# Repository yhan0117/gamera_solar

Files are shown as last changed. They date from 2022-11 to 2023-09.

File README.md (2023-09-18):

<!--
Hey, thanks for using the awesome-readme-template template.  
If you have any enhancements, then fork this project and create a pull request 
or just open an issue with the label "enhancement".

Don't forget to give this project a star for additional support ;)
Maybe you can mention me or this repo in the acknowledgements too
-->
<div align="center">

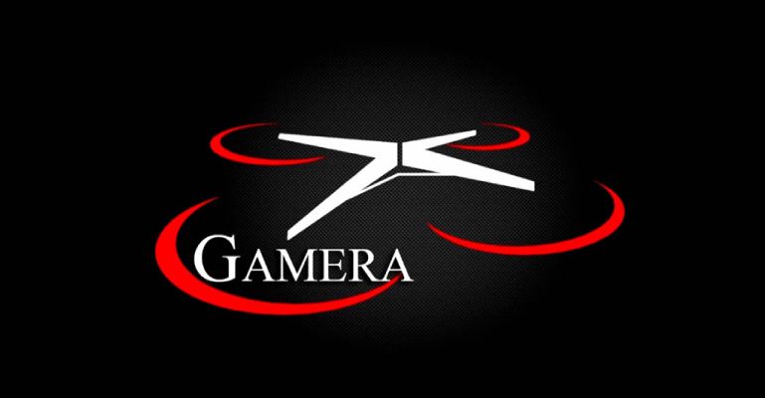
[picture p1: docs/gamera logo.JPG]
  
  <h1>Gamera Solar</h1>
  
  <p>
    An awesome README template for your projects! 
  </p>

<!-- Badges -->

<!-- Table of Contents -->
# :notebook_with_decorative_cover: Table of Contents

- [About the Project](#star2-about-the-project)
  * [Screenshots](#camera-screenshots)
  * [Tech Stack](#space_invader-tech-stack)
  * [Features](#dart-features)
  * [Color Reference](#art-color-reference)
  * [Environment Variables](#key-environment-variables)
- [Getting Started](#toolbox-getting-started)
  * [Prerequisites](#bangbang-prerequisites)
  * [Installation](#gear-installation)
  * [Running Tests](#test_tube-running-tests)
  * [Run Locally](#running-run-locally)
  * [Deployment](#triangular_flag_on_post-deployment)
- [Usage](#eyes-usage)
- [Roadmap](#compass-roadmap)
- [Contributing](#wave-contributing)
  * [Code of Conduct](#scroll-code-of-conduct)
- [FAQ](#grey_question-faq)
- [License](#warning-license)
- [Contact](#handshake-contact)
- [Acknowledgements](#gem-acknowledgements)

<!-- About the Project -->
## :star2: About the Project

<!-- Screenshots -->
### :camera: Screenshots

<div align="center"> 
  
</div>

<!-- TechStack -->
### :space_invader: Tech Stack

<details>
  <summary>Client</summary>
  <ul>
    <li><a href="https://www.typescriptlang.org/">Typescript</a></li>
    <li><a href="https://nextjs.org/">Next.js</a></li>
    <li><a href="https://reactjs.org/">React.js</a></li>
    <li><a href="https://tailwindcss.com/">TailwindCSS</a></li>
  </ul>
</details>

<details>
  <summary>Server</summary>
  <ul>
    <li><a href="https://www.typescriptlang.org/">Typescript</a></li>
    <li><a href="https://expressjs.com/">Express.js</a></li>
    <li><a href="https://go.dev/">Golang</a></li>
    <li><a href="https://nestjs.com/">Nest.js</a></li>
    <li><a href="https://socket.io/">SocketIO</a></li>
    <li><a href="https://www.prisma.io/">Prisma</a></li>    
    <li><a href="https://www.apollographql.com/">Apollo</a></li>
    <li><a href="https://graphql.org/">GraphQL</a></li>
  </ul>
</details>

<details>
<summary>Database</summary>
  <ul>
    <li><a href="https://www.mysql.com/">MySQL</a></li>
    <li><a href="https://www.postgresql.org/">PostgreSQL</a></li>
    <li><a href="https://redis.io/">Redis</a></li>
    <li><a href="https://neo4j.com/">Neo4j</a></li>
    <li><a href="https://www.mongodb.com/">MongoDB</a></li>
  </ul>
</details>

<details>
<summary>DevOps</summary>
  <ul>
    <li><a href="https://www.docker.com/">Docker</a></li>
    <li><a href="https://www.jenkins.io/">Jenkins</a></li>
    <li><a href="https://circleci.com/">CircleCLI</a></li>
  </ul>
</details>

<!-- Features -->
### :dart: Features

- Feature 1
- Feature 2
- Feature 3

<!-- Color Reference -->
### :art: Color Reference

| Color | Hex |
| --- | --- |
| Primary Color | #222831 #222831 |
| Secondary Color | #393E46 #393E46 |
| Accent Color | #00ADB5 #00ADB5 |
| Text Color | #EEEEEE #EEEEEE |

<!-- Env Variables -->
### :key: Environment Variables

To run this project, you will need to add the following environment variables to your .env file

`API_KEY`

`ANOTHER_API_KEY`

<!-- Getting Started -->
## 	:toolbox: Getting Started

<!-- Prerequisites -->
### :bangbang: Prerequisites

This project uses Yarn as package manager

```bash
 npm install --global yarn
```

<!-- Installation -->
### :gear: Installation

Install my-project with npm

```bash
  yarn install my-project
  cd my-project
```
   
<!-- Running Tests -->
### :test_tube: Running Tests

To run tests, run the following command

```bash
  yarn test test
```

<!-- Run Locally -->
### :running: Run Locally

Clone the project

```bash
  git clone https://github.com/Louis3797/awesome-readme-template.git
```

Go to the project directory

```bash
  cd my-project
```

Install dependencies

```bash
  yarn install
```

Start the server

```bash
  yarn start
```

<!-- Deployment -->
### :triangular_flag_on_post: Deployment

To deploy this project run

```bash
  yarn deploy
```

<!-- Usage -->
## :eyes: Usage

Use this space to tell a little more about your project and how it can be used. Show additional screenshots, code samples, demos or link to other resources.

```javascript
import Component from 'my-project'

function App() {
  return <Component />
}
```

<!-- Roadmap -->
## :compass: Roadmap

* [x] Todo 1
* [ ] Todo 2

<!-- Contributing -->
## :wave: Contributing

<a href="https://github.com/Louis3797/awesome-readme-template/graphs/contributors">
  
</a>

Contributions are always welcome!

See `contributing.md` for ways to get started.

<!-- Code of Conduct -->
### :scroll: Code of Conduct

Please read the [Code of Conduct](https://github.com/Louis3797/awesome-readme-template/blob/master/CODE_OF_CONDUCT.md)

<!-- FAQ -->
## :grey_question: FAQ

- Question 1

  + Answer 1

- Question 2

  + Answer 2

<!-- License -->
## :warning: License

Distributed under the no License. See LICENSE.txt for more information.

<!-- Contact -->
## :handshake: Contact

Your Name - [@twitter_handle](https://twitter.com/twitter_handle) - email@email_client.com

Project Link: [https://github.com/Louis3797/awesome-readme-template](https://github.com/Louis3797/awesome-readme-template)

<!-- Acknowledgments -->
## :gem: Acknowledgements

Use this section to mention useful resources and libraries that you have used in your projects.

 - [Shields.io](https://shields.io/)
 - [Awesome README](https://github.com/matiassingers/awesome-readme)
 - [Emoji Cheat Sheet](https://github.com/ikatyang/emoji-cheat-sheet/blob/master/README.md#travel--places)
 - [Readme Template](https://github.com/othneildrew/Best-README-Template)

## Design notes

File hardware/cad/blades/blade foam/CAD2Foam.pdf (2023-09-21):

Solidworks:
Given CAD model
In Solidworks (any CAD should work)
- Right click desired face
•
- Select “Export to DXF/DWG”
- (Relocate origin?)
- Save as desired file name and type (DXF for Mach 3) Open Mach3
- Under “File” click “LazyCam”
Open LazyCam
- Use “Open DXF” to open desired file with foam mode
- (Add step to allow for lead in/out)
- Select “Post Code”
- Save as Mach 3 file (.tap)
In Mach 3
•
- “Load G-Code
- Open desired .tap file
- Select “Tool Path” to double checkwire path
- Select “Program Run”

------------------------------------------------------------------------------------------------------------------------------------------.DAT Files
Given .dat file
Open .dat file
- “Select all”
- “Copy”
Open Microsoft Excel
- Click the arrow below “Paste”
- Under “Paste Options:” Click “Use Text Import Wizard…”
- Under “Original data type” make sure “Delimited” is selected
- Click “Next”
- Under “Data preview” you want to see two separate columns with a vertical line between. One will be your X coordinates, the other your Y coordinates. Depending on the .dat file this may already be the format as “Space” is the default delimiter. If it is not two separate columns, select “tab” or whatever was used in the .dat file to separate the columns.
- Once you have two separate columns of data, click “Finish”

•

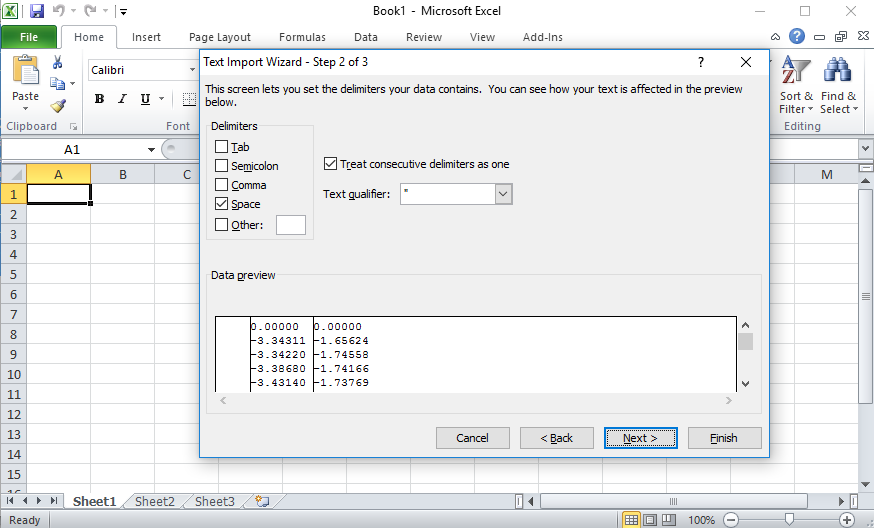
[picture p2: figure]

- If there is an empty column before you data, delete it
- Go to “File”, “Save As” and save as a “CSV (MS-DOS)(*.csv)” file with the name of your choice
- Find and open the folder containing the .csv file you just saved
- “Copy” and “Paste” the file in the same folder to duplicate it
- Rename the duplicated file to end in .scr (Ex: “SampleFile.scr”)
Open .scr file
- Add “PLINE” as the first line in the file
Open AutoCad
- Open a new drawing file
- Drag the .scr file into the drawing window. This should create a drawing that should look like the part you are trying to make.
- Type “c” to close the shape if your .scr file does not end at the same value that it begins

•

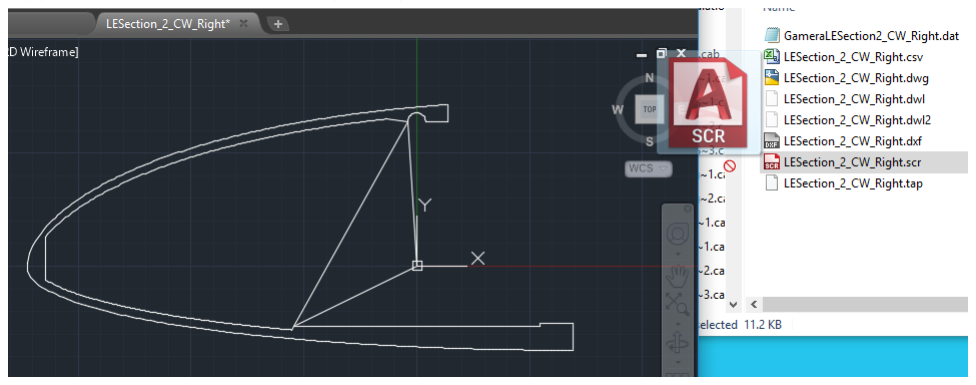
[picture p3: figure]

- Under “File” click “Save As” and save your drawing as a .dxf file (I used “AutoCad R12/LT2 DXF (*.dxf)” but do not know if there is a difference between .dxf formats)
- Close your drawing, if it prompts you to save as a drawing, you may save as a .dwg to backup
- LazyCam will not load your .dxf if it is open in AutoCad.
Open LazyCam
- Use “Open DXF” to open desired file. When prompted, select “Foam Mode”
- An image should be displayed as what you intend to cut
- Select “Post Code”
- Save as Mach 3 file (.tap)

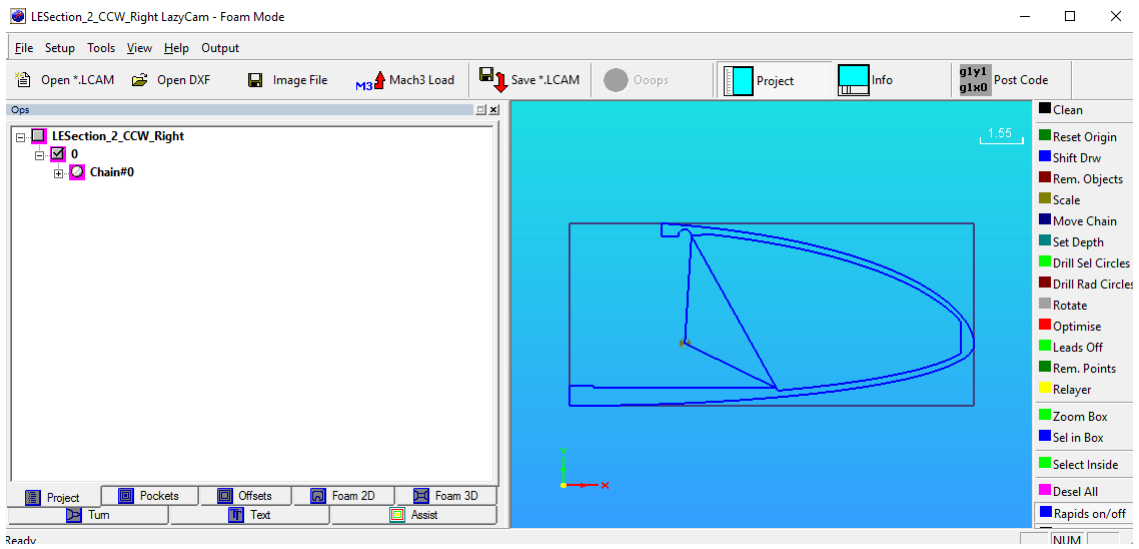
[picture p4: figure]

In Mach 3
- “Load G-Code
- Open desired .tap file
- Select “Tool Path” to double-check wire path
- Select “Program Run”

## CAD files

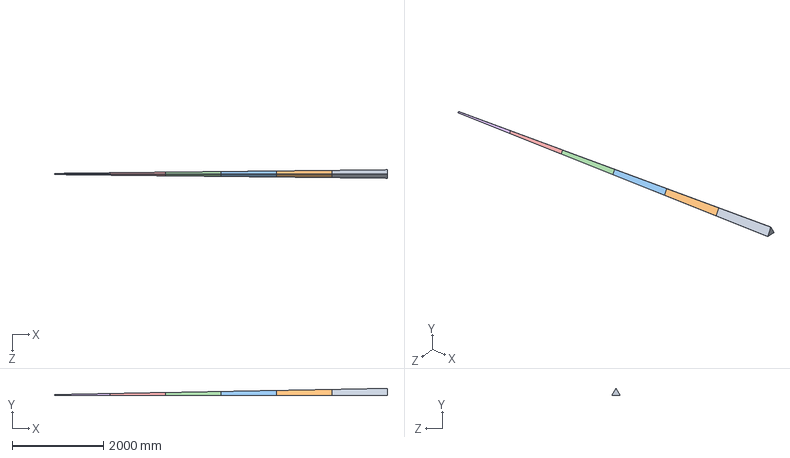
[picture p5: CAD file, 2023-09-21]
hardware/cad/blades/spar core/Blade Assembly.SLDASM
7315.0 x 159.8 x 187.7 mm
BladeSparCore1
BladeSparCore2
BladeSparCore3
BladeSparCore4
BladeSparCore5
BladeSparCore6

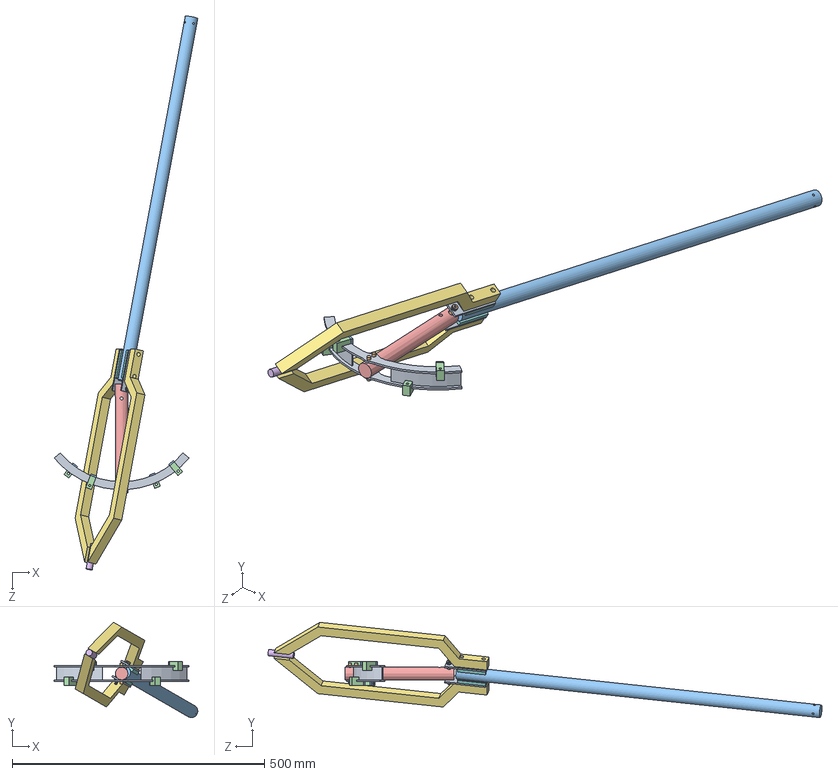
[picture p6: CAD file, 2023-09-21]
hardware/cad/rotor/landing gear/Landing_Gear.SLDASM
284.6 x 188.8 x 1097.5 mm
Hub_Crescent
Hub_Pin_A x 2
Hub_block_B x 4
Hub_block_A x 4
Hub_Shaft_CCW - Copy
LG tip-rod
LG strut x 2
Hub_plasticspacer x 2
Hub_metalspacer x 2
Shoulder Bolt
RotorShaft

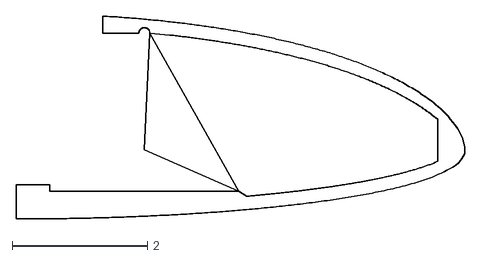
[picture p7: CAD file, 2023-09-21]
hardware/cad/blades/blade foam/dxf/LESection_3_CCW_Left.dxf
6.63 x 3.00

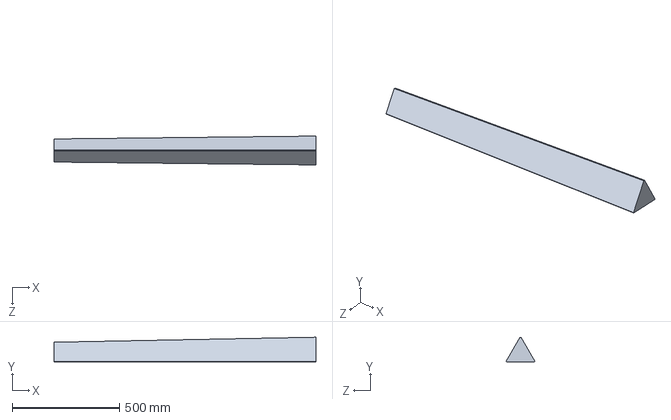
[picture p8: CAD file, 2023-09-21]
hardware/cad/blades/spar core/Core3/BladeSparCore3.SLDPRT
1219.2 x 114.4 x 134.4 mm

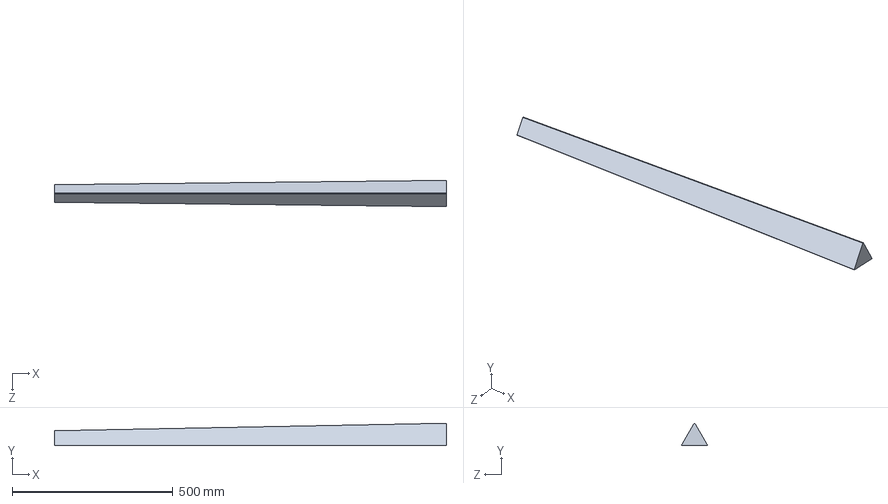
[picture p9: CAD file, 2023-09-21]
hardware/cad/blades/spar core/Core5/BladeSparCore5.SLDPRT
1219.2 x 69.9 x 81.7 mm

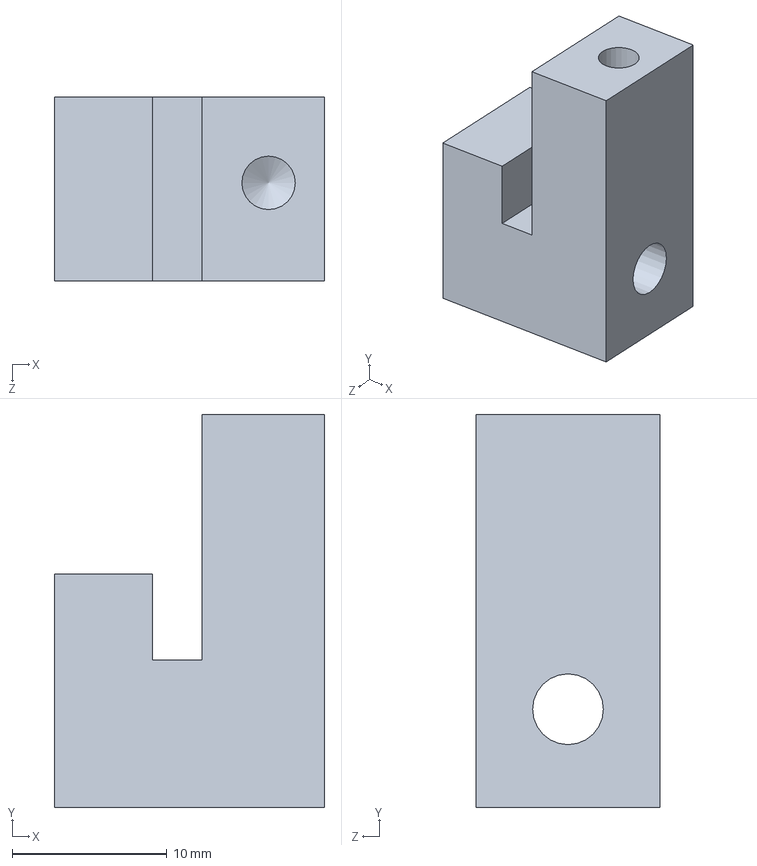
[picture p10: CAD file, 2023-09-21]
hardware/cad/rotor/hub/Hub_block_A.SLDPRT
17.5 x 25.4 x 11.9 mm

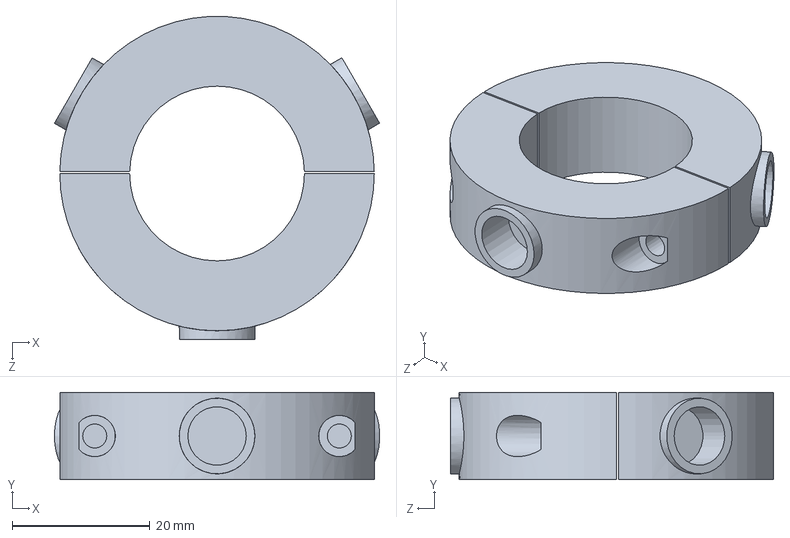
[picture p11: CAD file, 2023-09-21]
hardware/cad/rotor/shafts/shaft_collar_with_magnets.SLDPRT
47.3 x 12.7 x 47.0 mm

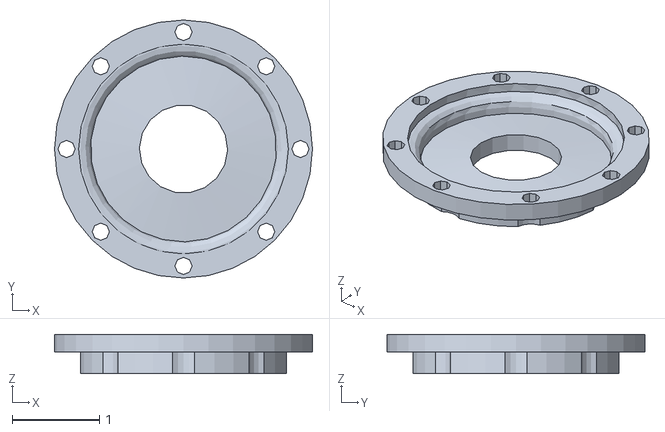
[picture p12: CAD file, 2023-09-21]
hardware/cad/rotor/transmission/Bottom Cap flat.stl
2.95 x 2.95 x 0.45

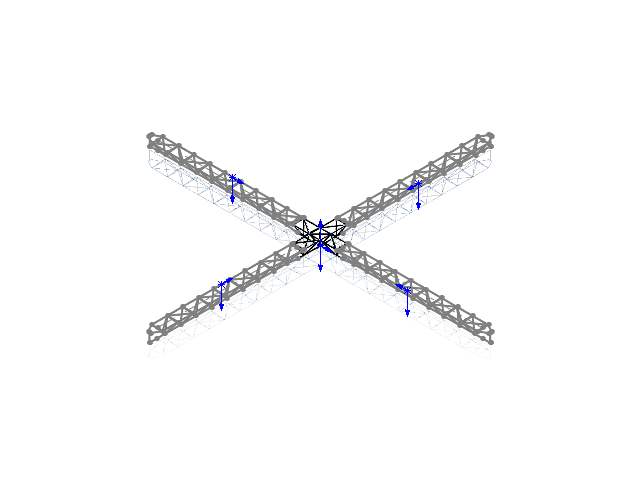
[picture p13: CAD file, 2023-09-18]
hardware/cad/airframe/airframe.SLDASM
CENTER(gamora)
ARM(Gamora) x 4

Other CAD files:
hardware/cad/blades/blade foam/section 1/LESection1_CCW_Left.dwg
hardware/cad/blades/blade foam/section 2/LESection_2_CW_Right.dwg
hardware/cad/blades/blade foam/section 3/LESection_3_CW_Right.dwg
hardware/cad/blades/blade foam/section 4/BladeSection_4_HollowTE_CW_Right.dwg
hardware/cad/blades/blade foam/section 5/BladeSection_5_CCW_Right.dwg
hardware/cad/blades/spar core/Core1 (Root)/BladeSparCore1_LeftFace.SLDPRT
hardware/cad/blades/spar core/Core2/BladeSparCore2_LeftFace.SLDPRT
hardware/cad/blades/spar core/Core4/BladeSparCore4_LeftFace.SLDPRT
hardware/cad/blades/spar core/Core6 (Tip)/BladeSparCore6_LeftFacepoints.DXF
hardware/cad/airframe/arm.SLDPRT
hardware/cad/airframe/center.SLDPRT
hardware/cad/blades/blade foam/dxf/BladeSection_4_HollowTE_CCW_Right.dxf
hardware/cad/blades/blade foam/dxf/BladeSection_4_HollowTE_CW_Right.dxf
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

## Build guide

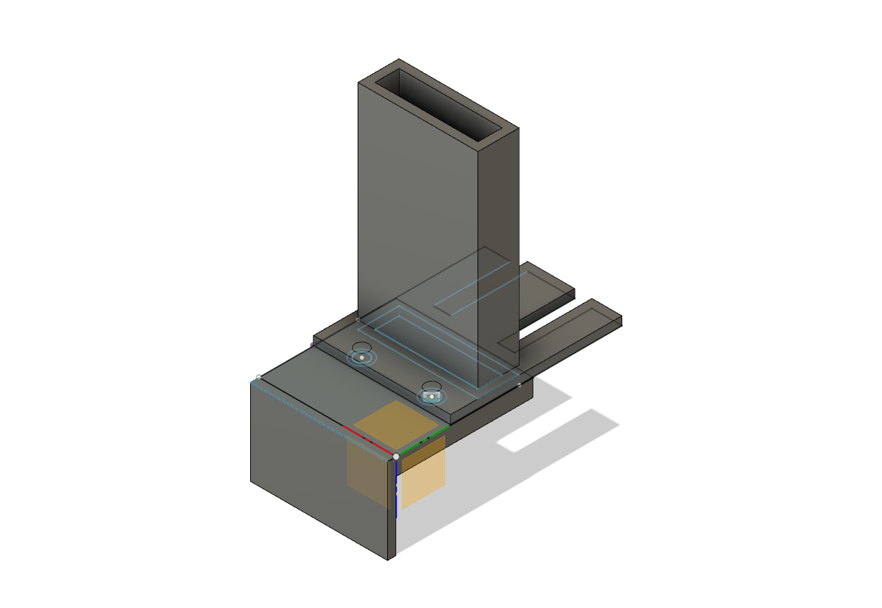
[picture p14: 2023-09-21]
testing/bbr/sensor mount/Assembly of sensor mount.png

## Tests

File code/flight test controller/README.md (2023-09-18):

firmware/src has the main.cpp file, which is the code you upload to the onboard MCU/ Arduino. In the loop() function, the script constantly monitors the Serial port (to be changed to radio) to read 4 int numbers,  do some conversions with the numbers, then send the value to the motor, via PWM with the command servo.write().\
control/read_keyboard.py is essentially the "controller" that uses the arrow keys as the joystick. It also loops indefinitely (in main function), read the keyboard input, keep track of the motor commands (the 4 int variables), and send to the MCU via Serial. \
The radio directory has two arduino files we used for testing the nRF24L01 modules. There's a transmit file and a receiver file, and those need to be uploaded to two separate MCUs, both connected to their own radio module based on the following schematic. Make sure you have steady and sufficient power source. More details on how to use those modules can be found in [Dejan's Blog](https://howtomechatronics.com/tutorials/arduino/arduino-wireless-communication-nrf24l01-tutorial/)\
schematic

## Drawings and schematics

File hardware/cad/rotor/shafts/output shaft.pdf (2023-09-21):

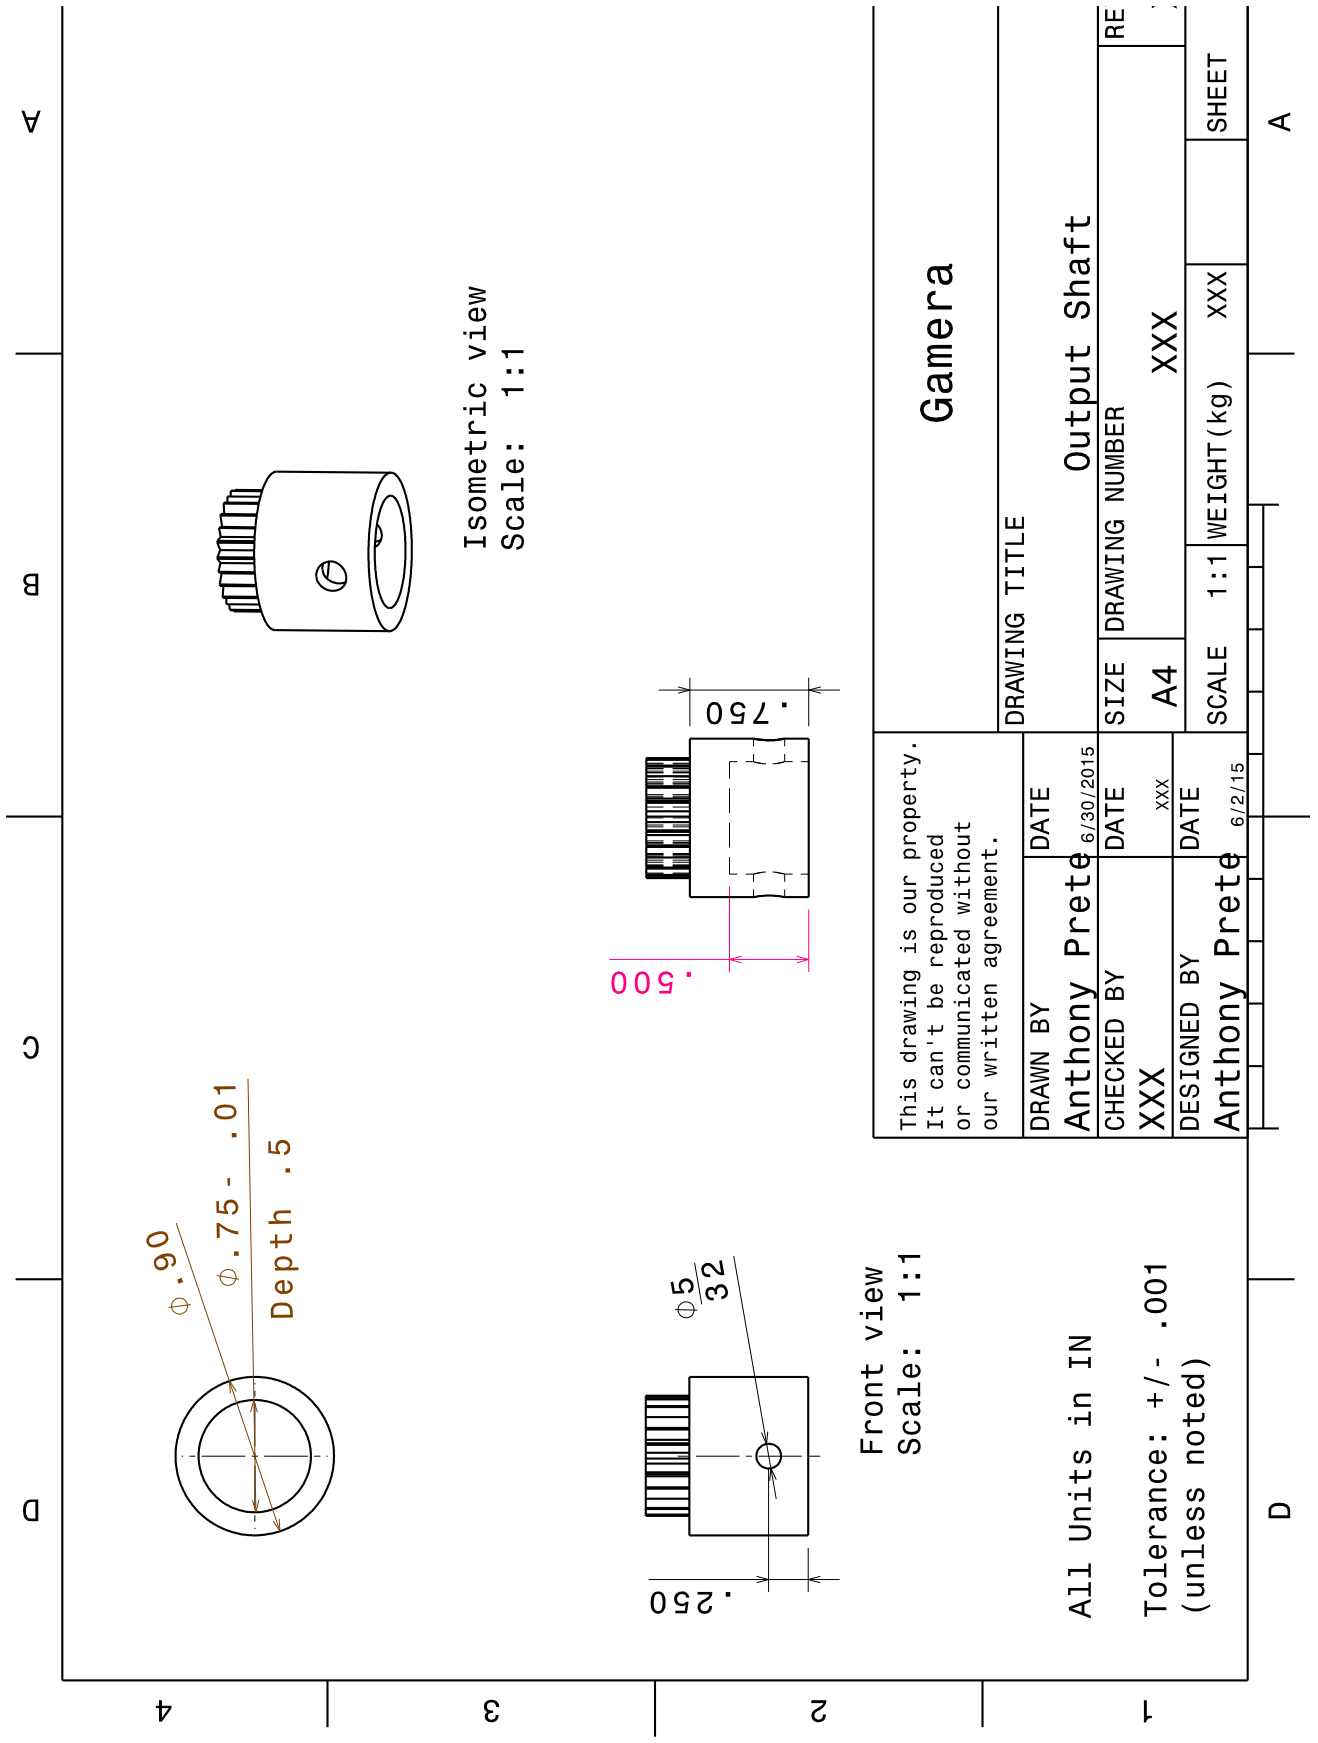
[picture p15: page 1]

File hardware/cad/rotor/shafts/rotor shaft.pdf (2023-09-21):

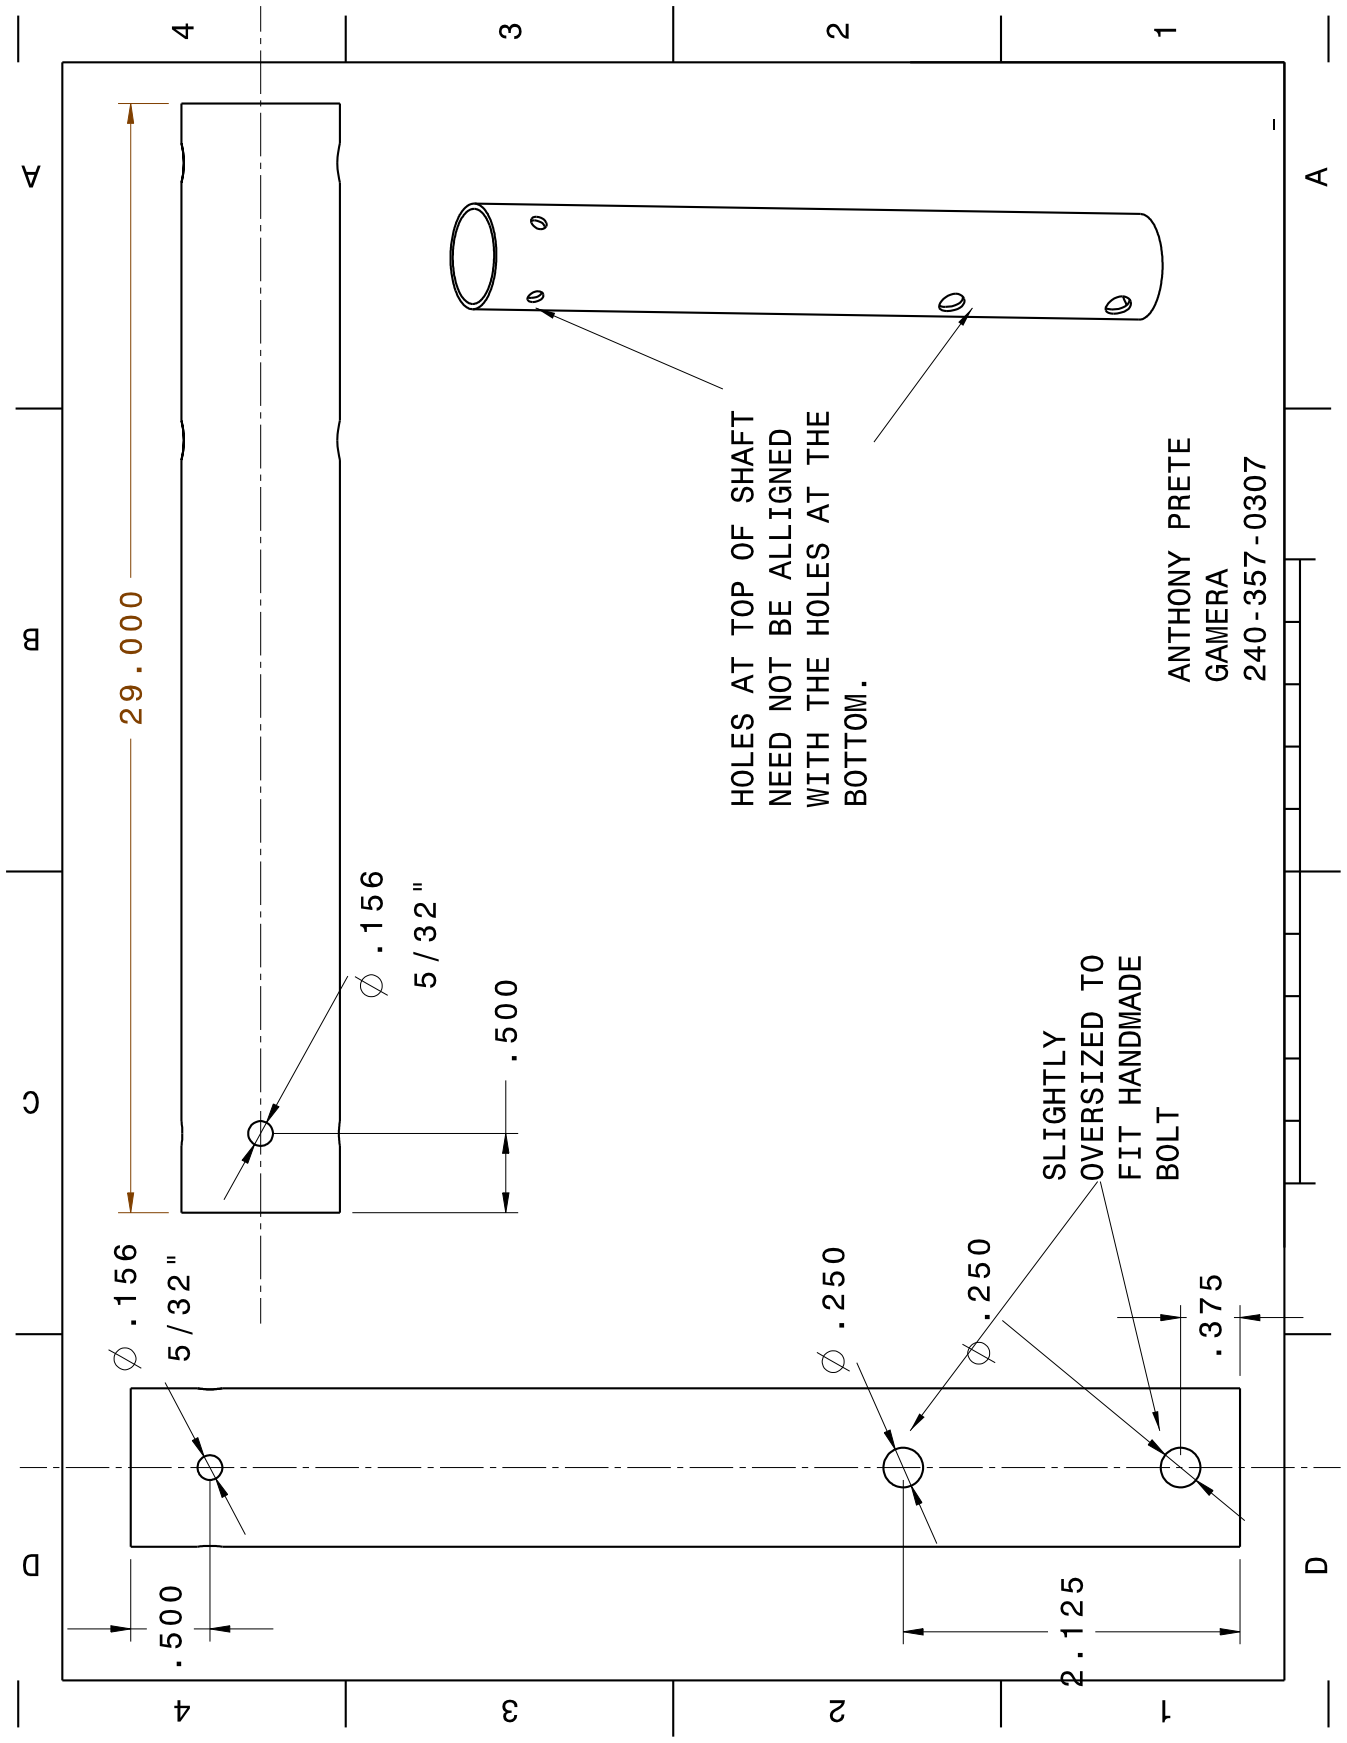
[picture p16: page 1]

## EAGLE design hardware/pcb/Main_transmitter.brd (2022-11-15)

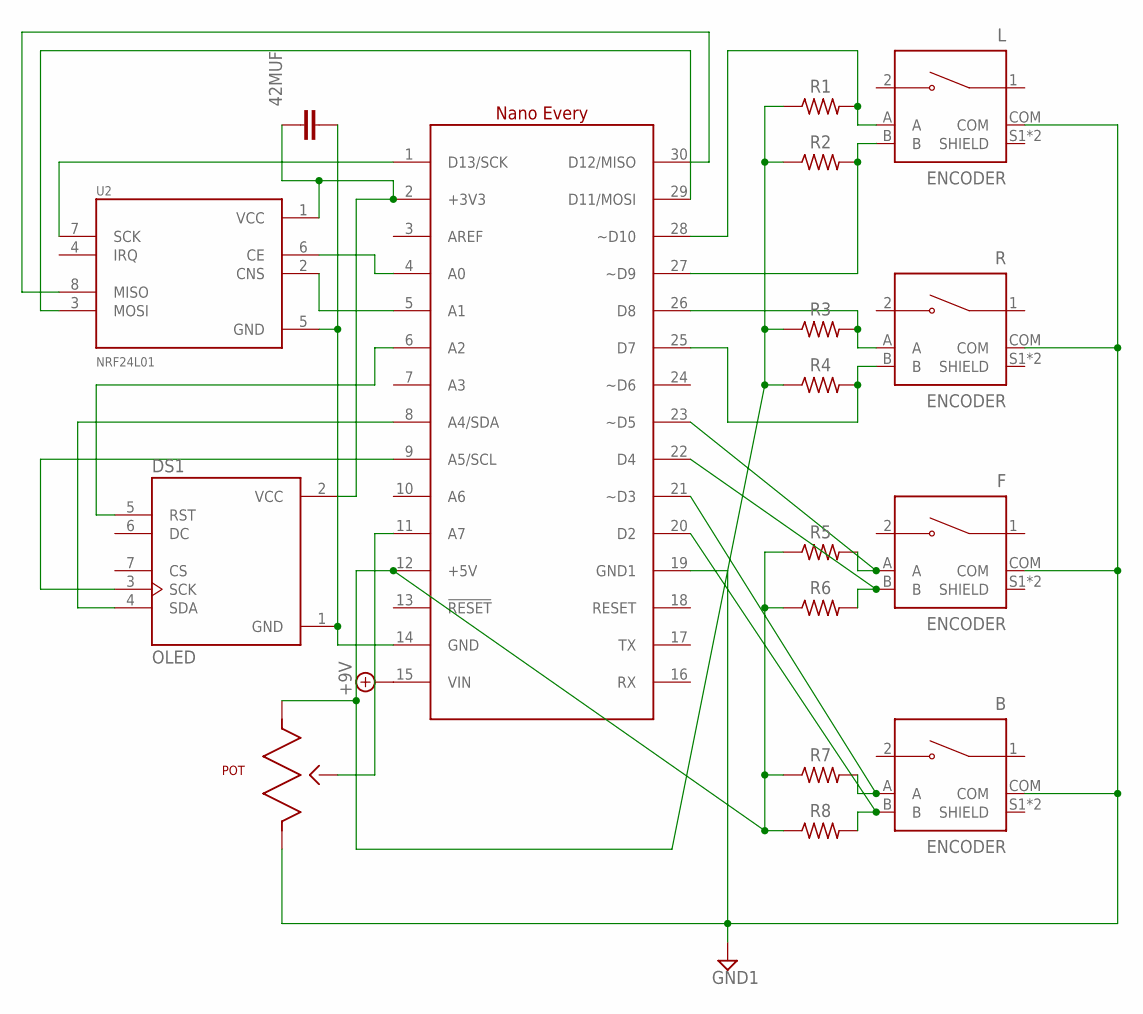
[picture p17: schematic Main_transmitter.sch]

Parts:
42MUF: C_RADIAL-12.5MM-DIA; CAPRD550W60D1025H1250B
B: ENCODER; XDCR_PEC11R-4215F-S0024
DS1: OLED
F: ENCODER; XDCR_PEC11R-4215F-S0024
L: ENCODER; XDCR_PEC11R-4215F-S0024
POT: POTENTIOMETER; P160
R: ENCODER; XDCR_PEC11R-4215F-S0024
R1, R2, R3, R4, R5, R6, R7, R8: R-US_AXIAL-7.2MM-PITCH; RESAD724W46L381D178B
U1: ARDUINONANO; NANO
U2: NRF24L01

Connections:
unnamed: L.A, R1.2, U1.28 (~D10)
unnamed: L.B, R2.2, U1.27 (~D9)
unnamed: R.A, R3.2, U1.26 (D8)
unnamed: R.B, R4.2, U1.25 (D7)
unnamed: F.A, R5.2, U1.23 (~D5)
unnamed: U1.4 (A0), U2.6 (CE)
unnamed: F.B, R6.2, U1.22 (D4)
unnamed: U1.5 (A1), U2.2 (CNS)
unnamed: B.A, R7.2, U1.21 (~D3)
unnamed: B.B, R8.2, U1.20 (D2)
unnamed: B.COM, F.COM, L.COM, POT.3, R.COM, U1.19 (GND1)
unnamed: U1.30 (D12/MISO), U2.8 (MISO)
unnamed: U1.29 (D11/MOSI), U2.3 (MOSI)
unnamed: POT.2, U1.11 (A7)
unnamed: DS1.3 (SCK), U1.9 (A5/SCL)
unnamed: DS1.4 (SDA), U1.8 (A4/SDA)
unnamed: 42MUF.1, DS1.2 (VCC), U1.2 (+3V3), U2.1 (VCC)
unnamed: 42MUF.2, DS1.1 (GND), U1.14 (GND), U2.5 (GND)
unnamed: U1.1 (D13/SCK), U2.7 (SCK)
unnamed: DS1.5 (RST), U1.6 (A2)
unnamed: POT.1, R1.1, R2.1, R3.1, R4.1, R5.1, R6.1, R7.1, R8.1, U1.12 (+5V)
VIN: U1.15 (VIN)

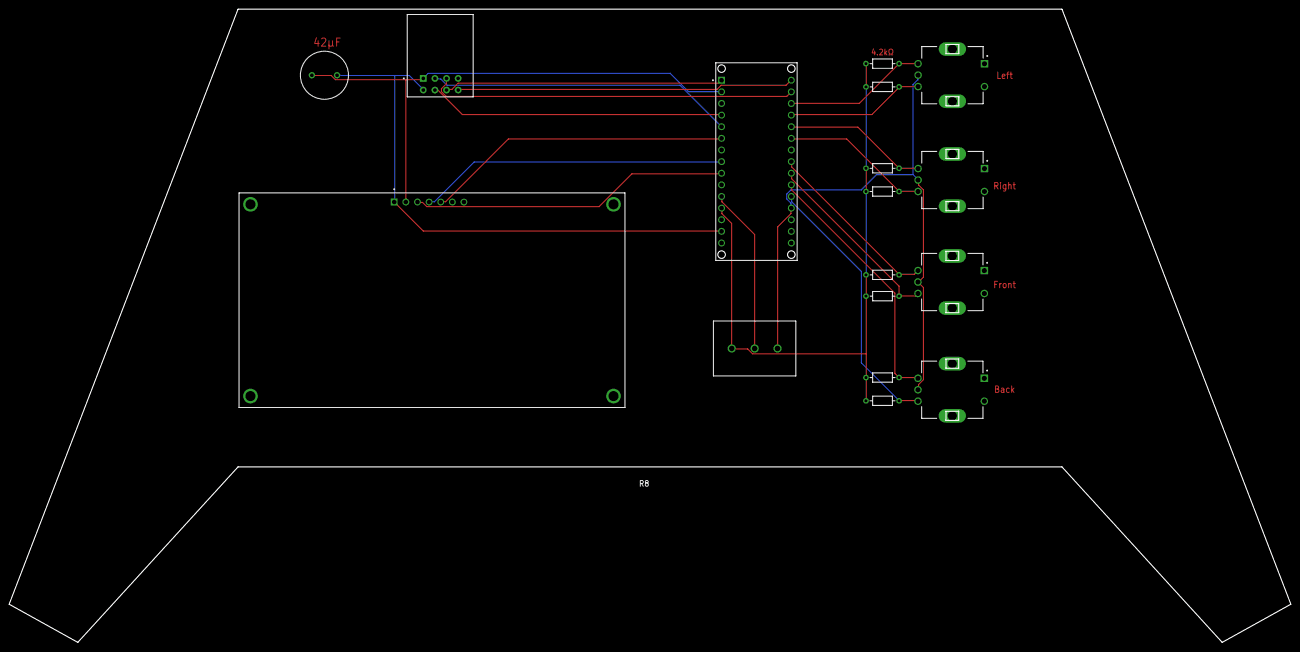
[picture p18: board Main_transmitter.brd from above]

Board: 2 copper layers, 280.0 x 138.3 mm, 17 parts (0 on the bottom side), 21 nets.

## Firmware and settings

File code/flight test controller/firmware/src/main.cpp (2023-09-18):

/*
BLDC controller based on keyboard input
*/

#include <Arduino.h>
#include <Servo.h>

#define MIN_SIGNAL 800
#define MAX_SIGNAL 2200

// read key vars
char key;
const int BUFFER_SIZE = 1;
char buf[2];

// motor struct
const int MOTOR_PIN[4] = {3,5,6,9};
struct MOTOR{
  Servo motor;
  int power;
};
struct MOTOR allMotors[4];

// function prototypes
void calibrate();
void quit();
void displayAllMotors();

// setup 
void setup() {
  // general config
  Serial.begin(115200);
  Serial.setTimeout(20);  
  pinMode(13, OUTPUT);

  // initialize motor
  for (int i = 0; i < 4; i++) {
    allMotors[i].motor.attach(MOTOR_PIN[i]);
    allMotors[i].power = MIN_SIGNAL;
    allMotors[i].motor.writeMicroseconds(MIN_SIGNAL);
  }

  // sync with main
  Serial.print(1);

  // wait for prompt to start 
  while (buf[1] != '\t')
      Serial.readBytes(buf, 2);
  buf[1] = ' ';

  // calibrate if required
  if (buf[0] == 'c')
    calibrate(); 

  // begin program
  Serial.println(0);
  // flash LED x5
  for(int i = 0; i < 5; i++) {
    digitalWrite(13,HIGH); 
    delay(100);
    digitalWrite(13,LOW);
    delay(100);
  }
}

// loop
void loop() {
  // reading key takes total of 20ms (based on timeout)
  Serial.readBytes(buf, BUFFER_SIZE);
  key = buf[0];

  switch (key) {
    // increase total throttle
    case 'H':
      for (int i = 0; i < 4; i++) {
        allMotors[i].power += 5;
        allMotors[i].power >= MAX_SIGNAL ? allMotors[i].power = MAX_SIGNAL : allMotors[i].power = allMotors[i].power; // saturate
      }
      displayAllMotors();
      digitalWrite(13,HIGH);  
      break;

    // decrease total throttle
    case 'P':
      for (int i = 0; i < 4; i++) {
        allMotors[i].power -= 5;
        allMotors[i].power <= MIN_SIGNAL ? allMotors[i].power = MIN_SIGNAL : allMotors[i].power = allMotors[i].power; // saturate
      }
      displayAllMotors();
      digitalWrite(13,HIGH);  
      break;

    // individual motor control => increase
    // blue
    case 'w':
      allMotors[0].power += 5;
      allMotors[0].power >= MAX_SIGNAL ? allMotors[0].power = MAX_SIGNAL : allMotors[0].power = allMotors[0].power; // saturate
      displayAllMotors();
      digitalWrite(13,HIGH);  
      break;

    // red
    case 'a':
      allMotors[1].power += 5;
      allMotors[1].power >= MAX_SIGNAL ? allMotors[1].power = MAX_SIGNAL : allMotors[1].power = allMotors[1].power; // saturate
      displayAllMotors();
      digitalWrite(13,HIGH);  
      break;

    // yellow
    case 's':
      allMotors[2].power += 5;
      allMotors[2].power >= MAX_SIGNAL ? allMotors[2].power = MAX_SIGNAL : allMotors[2].power = allMotors[2].power; // saturate
      displayAllMotors();
      digitalWrite(13,HIGH);  
      break;

    // pink
    case 'd':
      allMotors[3].power += 5;
      allMotors[3].power >= MAX_SIGNAL ? allMotors[3].power = MAX_SIGNAL : allMotors[3].power = allMotors[3].power; // saturate
      displayAllMotors();
      digitalWrite(13,HIGH);  
      break;

    // decrease
    // blue
    case 'W':
      allMotors[0].power -= 5;
      allMotors[0].power <= MIN_SIGNAL ? allMotors[0].power = MIN_SIGNAL : allMotors[0].power = allMotors[0].power; // saturate
      displayAllMotors();
      digitalWrite(13,HIGH);  
      break;

    // red
    case 'A':
      allMotors[1].power -= 5;
      allMotors[1].power <= MIN_SIGNAL ? allMotors[1].power = MIN_SIGNAL : allMotors[1].power = allMotors[1].power; // saturate
      displayAllMotors();
      digitalWrite(13,HIGH);  
      break;

    // yellow
    case 'S':
      allMotors[2].power -= 5;
      allMotors[2].power <= MIN_SIGNAL ? allMotors[2].power = MIN_SIGNAL : allMotors[2].power = allMotors[2].power; // saturate
      displayAllMotors();
      digitalWrite(13,HIGH);  
      break;

    // pink
    case 'D':
      allMotors[3].power -= 5;
      allMotors[3].power <= MIN_SIGNAL ? allMotors[3].power = MIN_SIGNAL : allMotors[3].power = allMotors[3].power; // saturate
      displayAllMotors();
      digitalWrite(13,HIGH);  
      break;

    // quit program
    case 'Q':
      quit();
  }

  delay(5);
  // update throttle
  for (int i = 0; i < 4; i++) {
    allMotors[i].motor.writeMicroseconds(allMotors[i].power);
  }  
  digitalWrite(13,LOW);
}

// ESC calibration routine
void calibrate() {
  // send max throttle
  for (int i = 0; i < 4; i++) {
    allMotors[i].motor.writeMicroseconds(MAX_SIGNAL);
  }

  // calibration begin, plug in power here
  // represented by 2
  Serial.println(2);

  // flash LED as indication
  for(int i = 0; i < 3; i++) {
    digitalWrite(13,HIGH); 
    delay(1000);
    digitalWrite(13,LOW);
    delay(1000);
  }

  // wait for tone to end then input
  while (buf[1] != '\t')
      Serial.readBytes(buf, 2);
  buf[1] = ' ';

  // sending min throttle
  // represented by 3
  Serial.println(3);
  for (int i = 0; i < 4; i++) {
    allMotors[i].motor.writeMicroseconds(MIN_SIGNAL);
  }
  // flash LED to indicate completion
  for(int i = 0; i < 3; i++) {
    digitalWrite(13,HIGH); 
    delay(1000);
    digitalWrite(13,LOW);
    delay(1000);
  }

  // power cycle now

  // wait for prompt to start
  while (buf[1] != '\t')
    Serial.readBytes(buf, 2);
}

void quit() {
  Serial.println(4);

  // LED 
  for (int i = 200; i > 0; i--) {
    float DC = i / 200.0;
    digitalWrite(13, 1);
    delayMicroseconds(floor(2000 * DC));
    digitalWrite(13, 0);
    delayMicroseconds(floor(2000 * (1 - DC)));
  }

  // decelerating motors
  int dp[4];
  for (int i = 0; i < 4; i++) { 
    dp[i]= allMotors[i].power - MIN_SIGNAL;
  }

  for (int i = 0; i <= 100; i++) {
    for (int i = 0; i < 4; i++) { 
      allMotors[i].power -= dp[i]/100;
      allMotors[i].motor.writeMicroseconds(allMotors[i].power);
    }
    delay(50);
  }

  // detach motors and Serial just in case
  Serial.println(5);
  for (int i = 0; i < 4; i++) { 
    allMotors[i].motor.detach();
  }
  Serial.end();

  // sleep forever until restart
  while (true){}
}

void displayAllMotors() {
  for (int i = 0; i < 4; i++) {
    Serial.print(allMotors[i].power);
    Serial.print('\t');
  }
  Serial.print('\n');
}

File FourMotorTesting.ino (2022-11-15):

#include <Servo.h>
#include <LiquidCrystal_I2C.h>
#include <Wire.h>
#define low 1000
#define high 2000

// set the LCD address to 0x27 for a 16 chars and 2 line display
LiquidCrystal_I2C lcd(0x27, 16, 2);

//struct storing all relevant data of an encoder-motor pair
typedef struct {
  //pins
  int A;
  int B;
  //rotation tracking
  int pos;
  //total power delivery
  int power;
  // debounce management
  boolean rotating;
  boolean A_set;
  boolean B_set;

  //interrupt timer
  volatile long curMicros;
} encoder;

Servo front;
Servo back;
Servo left;
Servo right;

//4 individual fine controllers
encoder control[4];
/*index and motor correspondence
  0: front
  1: back
  2: left
  3: right
*/

//enumerate encoder number
enum EncoderAssignments { f,
                          b,
                          l,
                          r };

//controls precision of each fine controller
int scalar = 10;
//master controller
int potVal;
int i;
long tt = 0;


void setup() {

  //LCD setup
  //initialize lcd screen
  // turn on the backlight
  lcd.init();

  lcd.backlight();


  //controls setup
  //set up each control
  //pin numbers
  /*
   L: 10,9
   R: 8,7
   F: 5,4
   B: 3,2
   */
  control[f].A = 46;
  control[f].B = 47;
  control[b].A = 48;
  control[b].B = 49;
  control[l].A = 50;
  control[l].B = 51;
  control[r].A = 52;
  control[r].B = 53;


  for (i = f; i <= r; i++) {

    //pin setup
    //no need for input pullup since pullup resistors are added physically
    pinMode(control[i].A, INPUT);
    pinMode(control[i].B, INPUT);

    //pin initialization
    digitalWrite(control[i].A, HIGH);
    digitalWrite(control[i].B, HIGH);

    //encoder initialization
    control[i].pos = 0;

    //debounce management
    control[i].A_set = false;
    control[i].B_set = false;
  }

  //initialize interrupt
  //need 8 fxns since interrupt routine cannot pass parameters
  attachInterrupt(digitalPinToInterrupt(control[f].A), fEncoderA, CHANGE);
  attachInterrupt(digitalPinToInterrupt(control[f].B), fEncoderB, CHANGE);
  attachInterrupt(digitalPinToInterrupt(control[b].A), bEncoderA, CHANGE);
  attachInterrupt(digitalPinToInterrupt(control[b].B), bEncoderB, CHANGE);
  attachInterrupt(digitalPinToInterrupt(control[l].A), lEncoderA, CHANGE);
  attachInterrupt(digitalPinToInterrupt(control[l].B), lEncoderB, CHANGE);
  attachInterrupt(digitalPinToInterrupt(control[r].A), rEncoderA, CHANGE);
  attachInterrupt(digitalPinToInterrupt(control[r].B), rEncoderB, CHANGE);

  //motor setup
  //pin assignments
  front.attach(3);
  back.attach(6);
  left.attach(9);
  right.attach(10);

  //initialize each motor
  front.writeMicroseconds(low);
  back.writeMicroseconds(low);
  left.writeMicroseconds(low);
  right.writeMicroseconds(low);

  Serial.begin(9600);
}

void loop() {
  // reset the debouncer
  for (i = f; i <= r; i++) {
    control[i].rotating = true;    
  }

  //read in master controller value
  potVal = analogRead(A0);

  for (i = f; i <= r; i++) {
    control[i].power = potVal + scalar * control[i].pos;

    if (control[i].power < 0) {
      control[i].power = 0;
      control[i].pos = -potVal / scalar;
    }

    if (control[i].power > 1023) {
      control[i].power = 1023;
      control[i].pos = (1023 - potVal) / scalar;
    }

    control[i].power = map(control[i].power, 0, 1023, low, high);
  }
  
  //temporarilyt disable interrupts so motors do not stutter
  //interrupt during signal delivery to motors create issues
  noInterrupts();

  //output PWM power signal to motor
  front.writeMicroseconds(control[f].power);
  back.writeMicroseconds(control[b].power);
  left.writeMicroseconds(control[l].power);
  right.writeMicroseconds(control[r].power);

  //reenable interrupts once time sensitive signals are sent
  interrupts();

  //display output on lcd
  //last digit is omitted to save space on display
  lcd.setCursor(0, 0);
  lcd.print("f ");
  lcd.print(control[f].power/10);

  lcd.setCursor(8, 0);
  lcd.print("b ");
  lcd.print(control[b].power/10);

  lcd.setCursor(0, 1);
  lcd.print("l ");
  lcd.print(control[l].power/10);

  lcd.setCursor(8, 1);
  lcd.print("r ");
  lcd.print(control[r].power/10);
}

//front
//Interrupt on A changing state
void fEncoderA() {
  //set debounce timer
  control[f].curMicros = micros(); 

  // debounce
  if (control[f].rotating){
    do{
    }while(micros() - control[f].curMicros < 1000);
  }  
  // wait a little until the bouncing is done
  // do not use delay or millis. they dont work because the function class already includes interrupt and Duue does not support twice interrupt 
  
  // Test transition, did things really change?
  if (digitalRead(control[f].A) != control[f].A_set) {  // debounce once more
    control[f].A_set = !control[f].A_set;

    // adjust counter + if A leads B
    if (control[f].A_set && !control[f].B_set)
      control[f].pos++;

    control[f].rotating = false;  // no more debouncing until loop() hits again
  }
}

// Interrupt on B changing state
void fEncoderB() {

  control[f].curMicros = micros(); 

  if (control[f].rotating){
    do{
    }while(micros() - control[f].curMicros < 1000);
  }  

  if (digitalRead(control[f].B) != control[f].B_set) {
    control[f].B_set = !control[f].B_set;

    //  adjust counter - 1 if B leads A
    if (control[f].B_set && !control[f].A_set)
      control[f].pos--;

    control[f].rotating = false;
  }
}

//back
void bEncoderA() {

  control[b].curMicros = micros(); 

  if (control[b].rotating){
    do{
    }while(micros() - control[b].curMicros < 1000);
  }  

  if (digitalRead(control[b].A) != control[b].A_set) {
    control[b].A_set = !control[b].A_set;

    if (control[b].A_set && !control[b].B_set)
      control[b].pos++;

    control[b].rotating = false;
  }
}

void bEncoderB() {

  control[b].curMicros = micros(); 

  if (control[b].rotating){
    do{
    }while(micros() - control[b].curMicros < 1000);
  }  

  if (digitalRead(control[b].B) != control[b].B_set) {
    control[b].B_set = !control[b].B_set;

    if (control[b].B_set && !control[b].A_set)
      control[b].pos--;

    control[b].rotating = false;
  }
}

//left
void lEncoderA() {

  control[l].curMicros = micros(); 

  if (control[l].rotating){
    do{
    }while(micros() - control[l].curMicros < 1000);
  }  

  if (digitalRead(control[l].A) != control[l].A_set) {
    control[l].A_set = !control[l].A_set;

    if (control[l].A_set && !control[l].B_set)
      control[l].pos++;

    control[l].rotating = false;
  }
}

void lEncoderB() {

  control[l].curMicros = micros(); 

  if (control[l].rotating){
    do{
    }while(micros() - control[l].curMicros < 1000);
  }  

  if (digitalRead(control[l].B) != control[l].B_set) {
    control[l].B_set = !control[l].B_set;

    if (control[l].B_set && !control[l].A_set)
      control[l].pos--;

    control[l].rotating = false;
  }
}
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

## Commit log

2023-08-28 reorganize project
    [Main_transmitter.brd, Main_transmitter.sch, Receiver.brd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]
2023-09-18 update structural asm
    [ARMGamora.SLDPRT, CENTERgamora.SLDPRT, GAMORA_Assembly.SLDASM]
2023-09-21 updated master cad
    [Hub_Crescent.SLDDRW, Hub_Crescent.SLDPRT, Hub_Pin_A.SLDPRT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]
